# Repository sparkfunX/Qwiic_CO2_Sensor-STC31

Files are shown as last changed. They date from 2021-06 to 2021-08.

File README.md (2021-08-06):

SparkX CO<sub>2</sub> Sensor - STC31 (Qwiic)
========================================

SparkX CO2 Sensor - STC31 (Qwiic) (SPX-18385) (https://www.sparkfun.com/products/18385)

[*SparkX CO2 Sensor - STC31 (Qwiic) (SPX-18385)*](https://www.sparkfun.com/products/18385)

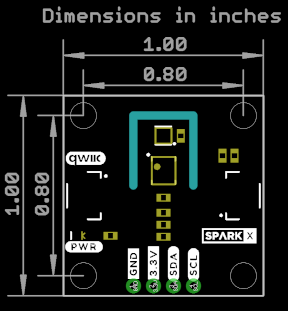
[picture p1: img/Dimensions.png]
SparkX CO2 Sensor - STC31 (Qwiic)


Do you need to be able to sense CO<sub>2</sub> concentrations of up to 100%? If so, the STC31 is the sensor for you!
The Sensirion STC31 thermal conductivity sensor has two CO<sub>2</sub> measurement ranges: 0 to 25 vol%; and 0 to 100 vol%.
The measurement repeatability is 0.2 vol%, with a stability of 0.025 vol% / °C.
The measurement accuracy depends on the measurement range: 0.5 vol% + 3% measured value; 1 vol% + 3% measured value.

Our breakout includes a separate SHTC3 humidity and temperature sensor; allowing the STC31 to deliver humidity-compensated
measurements together with improved temperature compensation. The STC31 can compensate for atmospheric pressure too - which is handy if,
like us, you’re up in the mountains!

The STC3x sensor family is Sensirion’s series of Gas Concentration sensors designed for high-volume applications.
The STC3x utilizes a revolutionized thermal conductivity measurement principle, which results in superior repeatability and long-term stability.
This makes the STC31 a perfect choice for applications where reliability is key.

The outstanding performance of these sensors is based on Sensirion’s patented CMOSens® sensor technology, which combines the sensor element,
signal processing and digital calibration on a small CMOS chip.
The well-proven CMOS technology is perfectly suited for high-quality mass production and is the ideal choice for demanding and cost-sensitive OEM applications.

Repository Contents
-------------------
* **/Documents** - datasheets etc.
* **/Hardware** - Eagle design files (.brd, .sch)
- **LICENSE.md** contains the licence information

Documentation
--------------
* **[STC3x Arduino Library](https://github.com/sparkfun/SparkFun_STC3x_Arduino_Library)** - Arduino library for the SparkX CO2 Sensor - STC31.
* **[Hookup Guide]()** - Basic hookup guide for the SparkX CO2 Sensor - STC31.

Product Versions
----------------
* [SPX-18385](https://www.sparkfun.com/products/18385) - Original SparkX Release.

License Information
-------------------

This product is _**open source**_!

Please review the LICENSE.md file for license information.

If you have any questions or concerns on licensing, please contact technical support on our [SparkFun forums](https://forum.sparkfun.com/viewforum.php?f=123).

Distributed as-is; no warranty is given.

- Your friends at SparkFun.

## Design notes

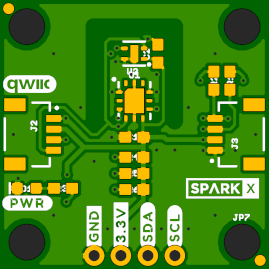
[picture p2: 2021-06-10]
img/Top.png

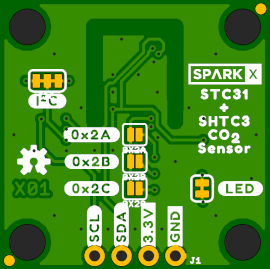
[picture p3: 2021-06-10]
img/Bottom.png

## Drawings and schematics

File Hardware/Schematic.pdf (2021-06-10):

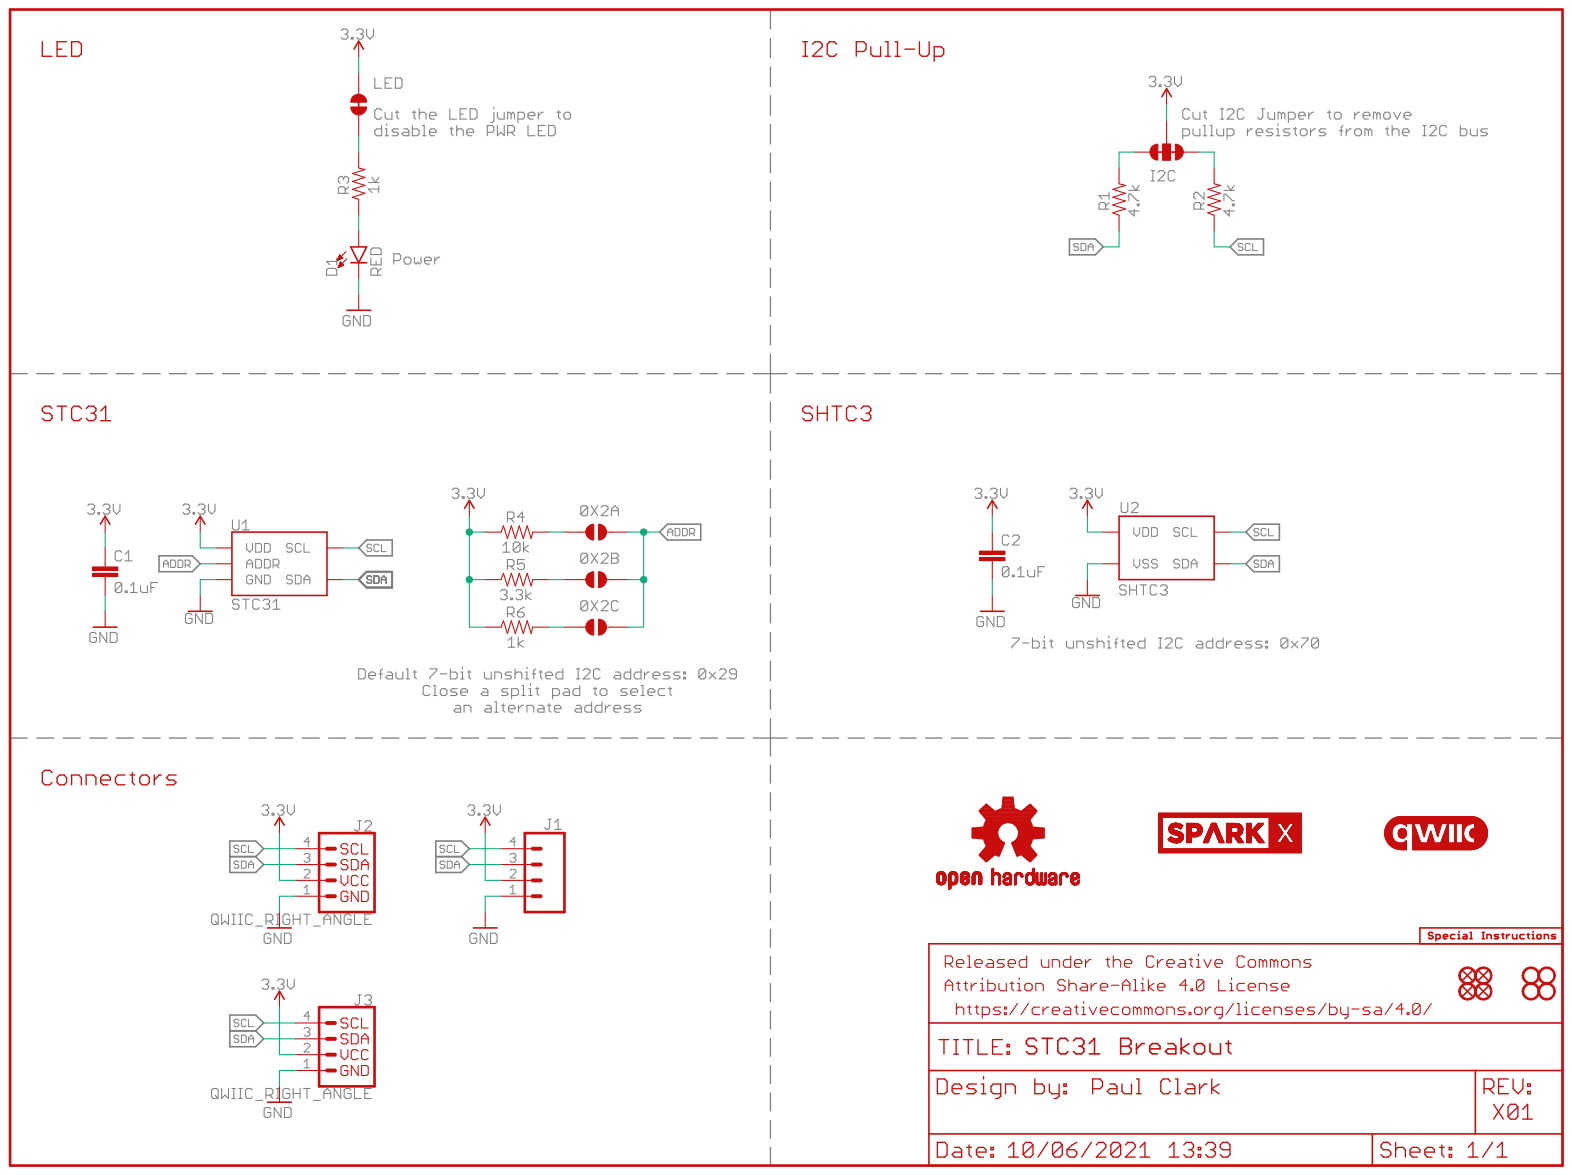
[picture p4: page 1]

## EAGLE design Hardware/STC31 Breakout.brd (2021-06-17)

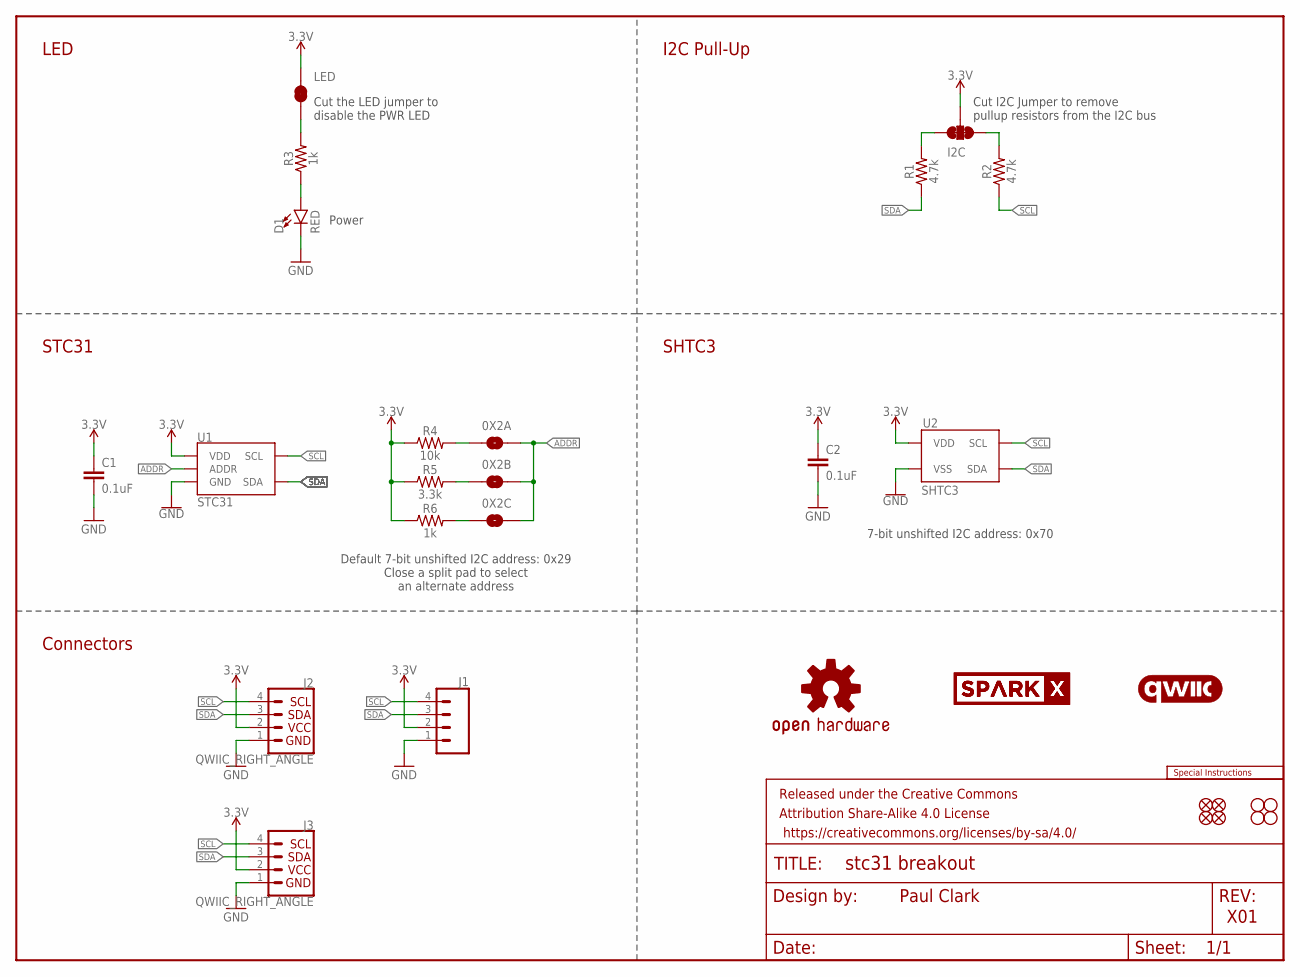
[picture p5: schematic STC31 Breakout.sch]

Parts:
0X2A, 0X2B, 0X2C: JUMPER-SMT_2_NO_SILK; SMT-JUMPER_2_NO_SILK
C1, C2: 0.1uF; 0603
D1: RED; LED-0603
FRAME1: FRAME-LETTER; CREATIVE_COMMONS
I2C: JUMPER-SMT_3_2-NC_TRACE_SILK; SMT-JUMPER_3_2-NC_TRACE_SILK
J1: CONN_041X04_NO_SILK; 1X04_NO_SILK
J2, J3: QWIIC_RIGHT_ANGLE; JST04_1MM_RA
JP1, JP2, JP5, JP6: FIDUCIAL1X2; FIDUCIAL-1X2
JP3, JP4, JP7, JP8: STAND-OFF
LED: JUMPER-SMT_2_NC_TRACE_SILK; SMT-JUMPER_2_NC_TRACE_SILK
LOGO1: SPECIAL_INSTRUCTIONS-ORDERING; ORDERING_INSTRUCTIONS
LOGO2: QWIIC_LOGO_5MM; QWIIC_5MM
LOGO5: OSHW-LOGOS; OSHW-LOGO-S
R1, R2: 4.7k; 0603
R3, R6: 1k; 0603
R4: 10k; 0603
R5: 3.3k; 0603
U1: STC31
U2: SHTC3
U$10, U$18: SPARKX-LOGO3; SPARKX-SMALL

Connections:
3.3V: C1.1, C2.1, I2C.2, J1.2, J2.2, J3.2, LED.2, R4.1, R5.1, R6.1, U1.6 (VDD), U2.1 (VDD)
ADDR: 0X2A.2, 0X2B.2, 0X2C.2, U1.3 (ADDR)
GND: C1.2, C2.2, D1.C, J1.1, J2.1, J3.1, U1.1 (GND), U1.5 (GND), U1.9 (GND), U1.11 (GND), U1.DIEPAD (GND), U2.4 (VSS), U2.5 (VSS)
unnamed: LED.1, R3.2
unnamed: I2C.3, R1.2
unnamed: D1.A, R3.1
unnamed: I2C.1, R2.2
unnamed: 0X2A.1, R4.2
unnamed: 0X2B.1, R5.2
unnamed: 0X2C.1, R6.2
SCL: J1.4, J2.4, J3.4, R2.1, U1.4 (SCL), U2.2 (SCL)
SDA: J1.3, J2.3, J3.3, R1.1, U1.7 (SDA), U2.3 (SDA)

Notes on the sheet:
Paul Clark
X01
7-bit unshifted I2C address: 0x70
Power
I2C Pull-Up
STC31
Connectors
Cut the LED jumper to disable the PWR LED
Cut I2C Jumper to remove pullup resistors from the I2C bus
LED
SHTC3
Default 7-bit unshifted I2C address: 0x29 Close a split pad to select an alternate address

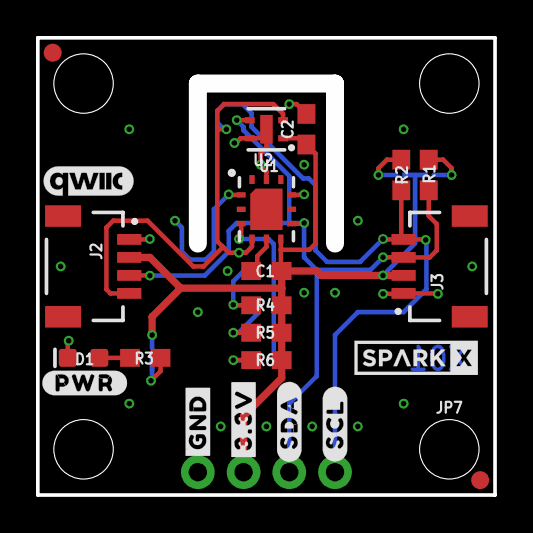
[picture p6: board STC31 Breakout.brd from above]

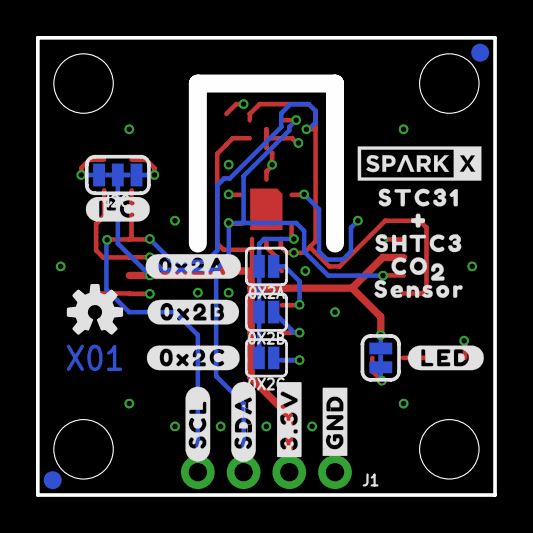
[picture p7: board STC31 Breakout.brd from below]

Board: 2 copper layers, 25.4 x 25.4 mm, 53 parts (25 on the bottom side), 12 nets.

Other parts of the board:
U$1, U$33: #GND#0
U$2, U$34: #3#3V#0
U$3, U$35: #SDA#0
U$4, U$36: #SCL#0
U$5: #LED#0
U$6: #0X2A#0
U$7: #0X2B#0
U$8: #0X2C#0
U$9: #I�C#0
U$11: STC310
U$12: #0
U$13: SHTC30
U$14: CO0
U$15: 20
U$16: SENSOR0
U$32: #PWR#0

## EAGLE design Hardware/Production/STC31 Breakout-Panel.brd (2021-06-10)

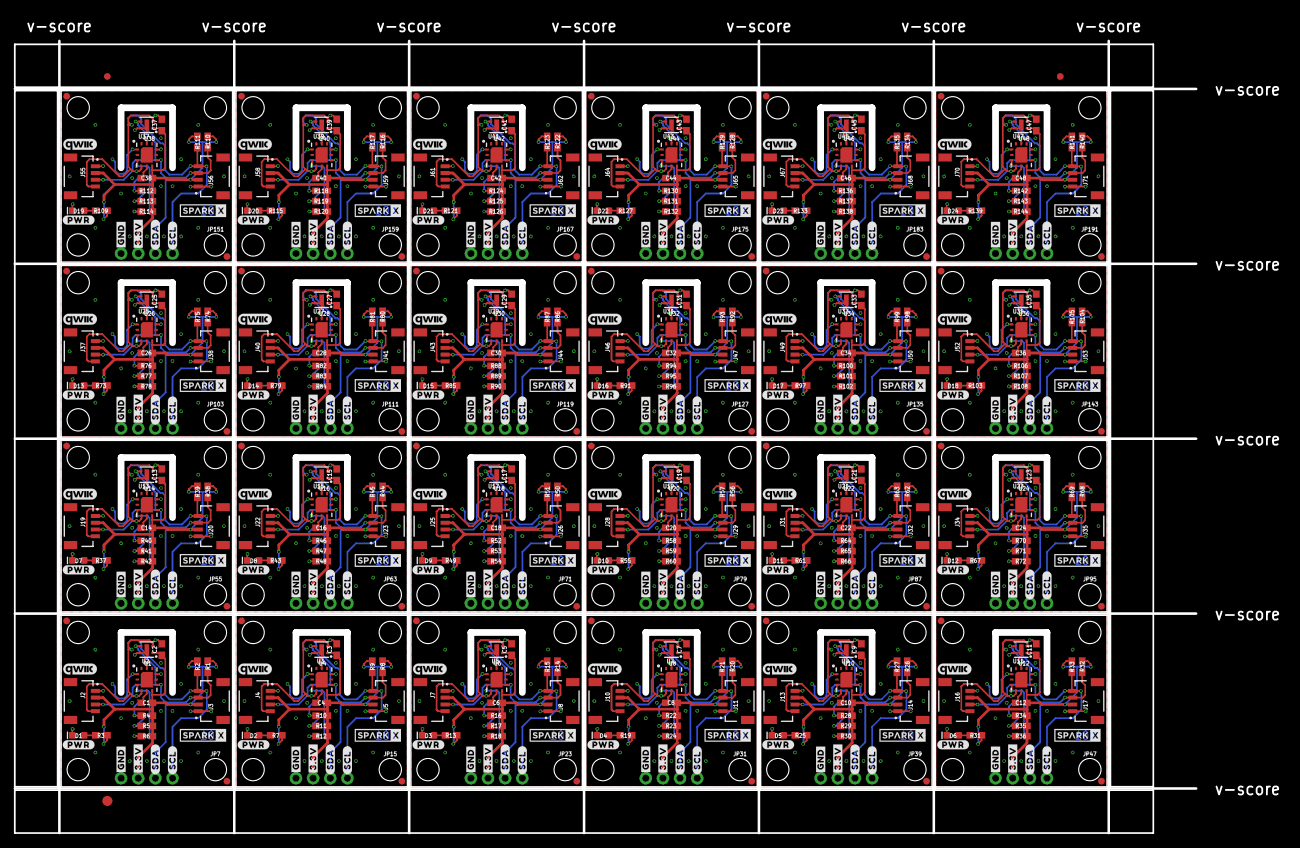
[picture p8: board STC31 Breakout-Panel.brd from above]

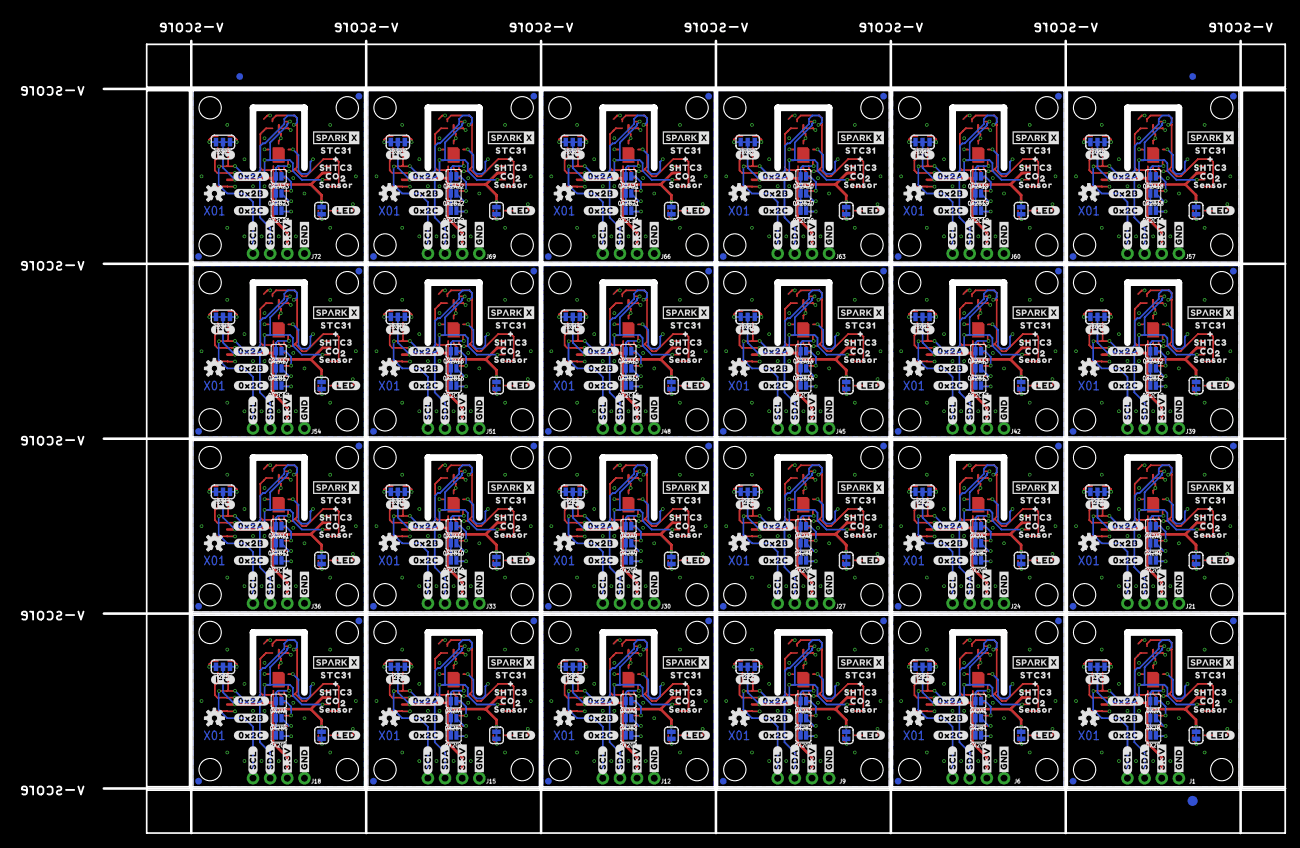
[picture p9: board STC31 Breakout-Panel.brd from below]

Board: 2 copper layers, 175.0 x 117.3 mm, 1230 parts (603 on the bottom side), 288 nets.

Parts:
0X2A, 0X2A1, 0X2A2, 0X2A3, 0X2A4, 0X2A5, 0X2A6, 0X2A7, 0X2A8, 0X2A9, 0X2A10, 0X2A11, 0X2A12, 0X2A13, 0X2A14, 0X2A15, 0X2A16, 0X2A17, 0X2A18, 0X2A19, 0X2A20, 0X2A21, 0X2A22, 0X2A23, 0X2B, 0X2B1, 0X2B2, 0X2B3, 0X2B4, 0X2B5, 0X2B6, 0X2B7, 0X2B8, 0X2B9, 0X2B10, 0X2B11, 0X2B12, 0X2B13, 0X2B14, 0X2B15, 0X2B16, 0X2B17, 0X2B18, 0X2B19, 0X2B20, 0X2B21, 0X2B22, 0X2B23, 0X2C, 0X2C1, 0X2C2, 0X2C3, 0X2C4, 0X2C5, 0X2C6, 0X2C7, 0X2C8, 0X2C9, 0X2C10, 0X2C11, 0X2C12, 0X2C13, 0X2C14, 0X2C15, 0X2C16, 0X2C17, 0X2C18, 0X2C19, 0X2C20, 0X2C21, 0X2C22, 0X2C23: JUMPER-SMT_2_NO_SILK; SMT-JUMPER_2_NO_SILK
C1, C2, C3, C4, C5, C6, C7, C8, C9, C10, C11, C12, C13, C14, C15, C16, C17, C18, C19, C20, C21, C22, C23, C24, C25, C26, C27, C28, C29, C30, C31, C32, C33, C34, C35, C36, C37, C38, C39, C40, C41, C42, C43, C44, C45, C46, C47, C48: 0.1uF; 0603
D1, D2, D3, D4, D5, D6, D7, D8, D9, D10, D11, D12, D13, D14, D15, D16, D17, D18, D19, D20, D21, D22, D23, D24: RED; LED-0603
E$1, E$2, E$3, E$4: FIDUCIAL-1X2
E$5, E$6: FIDUCIAL-1.5X3
I2C, I2C1, I2C2, I2C3, I2C4, I2C5, I2C6, I2C7, I2C8, I2C9, I2C10, I2C11, I2C12, I2C13, I2C14, I2C15, I2C16, I2C17, I2C18, I2C19, I2C20, I2C21, I2C22, I2C23: JUMPER-SMT_3_2-NC_TRACE_SILK; SMT-JUMPER_3_2-NC_TRACE_SILK
J1, J6, J9, J12, J15, J18, J21, J24, J27, J30, J33, J36, J39, J42, J45, J48, J51, J54, J57, J60, J63, J66, J69, J72: 1X04_NO_SILK
J2, J3, J4, J5, J7, J8, J10, J11, J13, J14, J16, J17, J19, J20, J22, J23, J25, J26, J28, J29, J31, J32, J34, J35, J37, J38, J40, J41, J43, J44, J46, J47, J49, J50, J52, J53, J55, J56, J58, J59, J61, J62, J64, J65, J67, J68, J70, J71: QWIIC_RIGHT_ANGLE; JST04_1MM_RA
JP1, JP2, JP5, JP6, JP11, JP12, JP13, JP14, JP19, JP20, JP21, JP22, JP27, JP28, JP29, JP30, JP35, JP36, JP37, JP38, JP43, JP44, JP45, JP46, JP51, JP52, JP53, JP54, JP59, JP60, JP61, JP62, JP67, JP68, JP69, JP70, JP75, JP76, JP77, JP78, JP83, JP84, JP85, JP86, JP91, JP92, JP93, JP94, JP99, JP100, JP101, JP102, JP107, JP108, JP109, JP110, JP115, JP116, JP117, JP118, JP123, JP124, JP125, JP126, JP131, JP132, JP133, JP134, JP139, JP140, JP141, JP142, JP147, JP148, JP149, JP150, JP155, JP156, JP157, JP158, JP163, JP164, JP165, JP166, JP171, JP172, JP173, JP174, JP179, JP180, JP181, JP182, JP187, JP188, JP189, JP190: FIDUCIAL1X2; FIDUCIAL-1X2
JP3, JP4, JP7, JP8, JP9, JP10, JP15, JP16, JP17, JP18, JP23, JP24, JP25, JP26, JP31, JP32, JP33, JP34, JP39, JP40, JP41, JP42, JP47, JP48, JP49, JP50, JP55, JP56, JP57, JP58, JP63, JP64, JP65, JP66, JP71, JP72, JP73, JP74, JP79, JP80, JP81, JP82, JP87, JP88, JP89, JP90, JP95, JP96, JP97, JP98, JP103, JP104, JP105, JP106, JP111, JP112, JP113, JP114, JP119, JP120, JP121, JP122, JP127, JP128, JP129, JP130, JP135, JP136, JP137, JP138, JP143, JP144, JP145, JP146, JP151, JP152, JP153, JP154, JP159, JP160, JP161, JP162, JP167, JP168, JP169, JP170, JP175, JP176, JP177, JP178, JP183, JP184, JP185, JP186, JP191, JP192: STAND-OFF
LED, LED1, LED2, LED3, LED4, LED5, LED6, LED7, LED8, LED9, LED10, LED11, LED12, LED13, LED14, LED15, LED16, LED17, LED18, LED19, LED20, LED21, LED22, LED23: JUMPER-SMT_2_NC_TRACE_SILK; SMT-JUMPER_2_NC_TRACE_SILK
LOGO1, LOGO4, LOGO5, LOGO7, LOGO9, LOGO11, LOGO13, LOGO15, LOGO17, LOGO19, LOGO21, LOGO23, LOGO25, LOGO27, LOGO29, LOGO31, LOGO33, LOGO35, LOGO37, LOGO39, LOGO41, LOGO43, LOGO45, LOGO47: OSHW-LOGOS; OSHW-LOGO-S
LOGO2, LOGO3, LOGO6, LOGO8, LOGO10, LOGO12, LOGO14, LOGO16, LOGO18, LOGO20, LOGO22, LOGO24, LOGO26, LOGO28, LOGO30, LOGO32, LOGO34, LOGO36, LOGO38, LOGO40, LOGO42, LOGO44, LOGO46, LOGO48: QWIIC_LOGO_5MM; QWIIC_5MM
R1, R2, R8, R9, R14, R15, R20, R21, R26, R27, R32, R33, R38, R39, R44, R45, R50, R51, R56, R57, R62, R63, R68, R69, R74, R75, R80, R81, R86, R87, R92, R93, R98, R99, R104, R105, R110, R111, R116, R117, R122, R123, R128, R129, R134, R135, R140, R141: 4.7k; 0603
R3, R6, R7, R12, R13, R18, R19, R24, R25, R30, R31, R36, R37, R42, R43, R48, R49, R54, R55, R60, R61, R66, R67, R72, R73, R78, R79, R84, R85, R90, R91, R96, R97, R102, R103, R108, R109, R114, R115, R120, R121, R126, R127, R132, R133, R138, R139, R144: 1k; 0603
R4, R10, R16, R22, R28, R34, R40, R46, R52, R58, R64, R70, R76, R82, R88, R94, R100, R106, R112, R118, R124, R130, R136, R142: 10k; 0603
R5, R11, R17, R23, R29, R35, R41, R47, R53, R59, R65, R71, R77, R83, R89, R95, R101, R107, R113, R119, R125, R131, R137, R143: 3.3k; 0603
U1, U4, U6, U8, U10, U12, U14, U16, U18, U20, U22, U24, U26, U28, U30, U32, U34, U36, U38, U40, U42, U44, U46, U48: STC31
U2, U3, U5, U7, U9, U11, U13, U15, U17, U19, U21, U23, U25, U27, U29, U31, U33, U35, U37, U39, U41, U43, U45, U47: SHTC3
U$1, U$21, U$25, U$33, U$48, U$52, U$70, U$74, U$92, U$96, U$114, U$118, U$136, U$140, U$158, U$162, U$180, U$184, U$202, U$206, U$224, U$228, U$246, U$250, U$268, U$272, U$290, U$294, U$312, U$316, U$334, U$338, U$356, U$360, U$378, U$382, U$400, U$404, U$422, U$426, U$444, U$448, U$466, U$470, U$488, U$492, U$510, U$514: #GND#0
U$2, U$22, U$26, U$34, U$49, U$53, U$71, U$75, U$93, U$97, U$115, U$119, U$137, U$141, U$159, U$163, U$181, U$185, U$203, U$207, U$225, U$229, U$247, U$251, U$269, U$273, U$291, U$295, U$313, U$317, U$335, U$339, U$357, U$361, U$379, U$383, U$401, U$405, U$423, U$427, U$445, U$449, U$467, U$471, U$489, U$493, U$511, U$515: #3#3V#0
U$3, U$23, U$27, U$35, U$50, U$54, U$72, U$76, U$94, U$98, U$116, U$120, U$138, U$142, U$160, U$164, U$182, U$186, U$204, U$208, U$226, U$230, U$248, U$252, U$270, U$274, U$292, U$296, U$314, U$318, U$336, U$340, U$358, U$362, U$380, U$384, U$402, U$406, U$424, U$428, U$446, U$450, U$468, U$472, U$490, U$494, U$512, U$516: #SDA#0
U$4, U$24, U$28, U$36, U$51, U$55, U$73, U$77, U$95, U$99, U$117, U$121, U$139, U$143, U$161, U$165, U$183, U$187, U$205, U$209, U$227, U$231, U$249, U$253, U$271, U$275, U$293, U$297, U$315, U$319, U$337, U$341, U$359, U$363, U$381, U$385, U$403, U$407, U$425, U$429, U$447, U$451, U$469, U$473, U$491, U$495, U$513, U$517: #SCL#0
U$5, U$29, U$56, U$78, U$100, U$122, U$144, U$166, U$188, U$210, U$232, U$254, U$276, U$298, U$320, U$342, U$364, U$386, U$408, U$430, U$452, U$474, U$496, U$518: #LED#0
U$6, U$30, U$57, U$79, U$101, U$123, U$145, U$167, U$189, U$211, U$233, U$255, U$277, U$299, U$321, U$343, U$365, U$387, U$409, U$431, U$453, U$475, U$497, U$519: #0X2A#0
U$7, U$31, U$58, U$80, U$102, U$124, U$146, U$168, U$190, U$212, U$234, U$256, U$278, U$300, U$322, U$344, U$366, U$388, U$410, U$432, U$454, U$476, U$498, U$520: #0X2B#0
U$8, U$37, U$59, U$81, U$103, U$125, U$147, U$169, U$191, U$213, U$235, U$257, U$279, U$301, U$323, U$345, U$367, U$389, U$411, U$433, U$455, U$477, U$499, U$521: #0X2C#0
U$9, U$38, U$60, U$82, U$104, U$126, U$148, U$170, U$192, U$214, U$236, U$258, U$280, U$302, U$324, U$346, U$368, U$390, U$412, U$434, U$456, U$478, U$500, U$522: #I�C#0
U$10, U$17, U$18, U$19, U$45, U$46, U$67, U$68, U$89, U$90, U$111, U$112, U$133, U$134, U$155, U$156, U$177, U$178, U$199, U$200, U$221, U$222, U$243, U$244, U$265, U$266, U$287, U$288, U$309, U$310, U$331, U$332, U$353, U$354, U$375, U$376, U$397, U$398, U$419, U$420, U$441, U$442, U$463, U$464, U$485, U$486, U$507, U$508: SPARKX-LOGO3; SPARKX-SMALL
U$11, U$39, U$61, U$83, U$105, U$127, U$149, U$171, U$193, U$215, U$237, U$259, U$281, U$303, U$325, U$347, U$369, U$391, U$413, U$435, U$457, U$479, U$501, U$523: STC310
U$12, U$40, U$62, U$84, U$106, U$128, U$150, U$172, U$194, U$216, U$238, U$260, U$282, U$304, U$326, U$348, U$370, U$392, U$414, U$436, U$458, U$480, U$502, U$524: #0
U$13, U$41, U$63, U$85, U$107, U$129, U$151, U$173, U$195, U$217, U$239, U$261, U$283, U$305, U$327, U$349, U$371, U$393, U$415, U$437, U$459, U$481, U$503, U$525: SHTC30
U$14, U$42, U$64, U$86, U$108, U$130, U$152, U$174, U$196, U$218, U$240, U$262, U$284, U$306, U$328, U$350, U$372, U$394, U$416, U$438, U$460, U$482, U$504, U$526: CO0
U$15, U$43, U$65, U$87, U$109, U$131, U$153, U$175, U$197, U$219, U$241, U$263, U$285, U$307, U$329, U$351, U$373, U$395, U$417, U$439, U$461, U$483, U$505, U$527: 20
U$16, U$44, U$66, U$88, U$110, U$132, U$154, U$176, U$198, U$220, U$242, U$264, U$286, U$308, U$330, U$352, U$374, U$396, U$418, U$440, U$462, U$484, U$506, U$528: SENSOR0
U$20, U$32, U$47, U$69, U$91, U$113, U$135, U$157, U$179, U$201, U$223, U$245, U$267, U$289, U$311, U$333, U$355, U$377, U$399, U$421, U$443, U$465, U$487, U$509: #PWR#0

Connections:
3.3V: C1.1, C2.1, I2C.2, J1.2, J2.2, J3.2, LED.2, R4.1, R5.1, R6.1, U1.6, U2.1
3.3V1: C3.1, C4.1, I2C1.2, J4.2, J5.2, J6.2, LED1.2, R10.1, R11.1, R12.1, U3.1, U4.6
3.3V2: C5.1, C6.1, I2C2.2, J7.2, J8.2, J9.2, LED2.2, R16.1, R17.1, R18.1, U5.1, U6.6
3.3V3: C7.1, C8.1, I2C3.2, J10.2, J11.2, J12.2, LED3.2, R22.1, R23.1, R24.1, U7.1, U8.6
3.3V4: C9.1, C10.1, I2C4.2, J13.2, J14.2, J15.2, LED4.2, R28.1, R29.1, R30.1, U9.1, U10.6
3.3V5: C11.1, C12.1, I2C5.2, J16.2, J17.2, J18.2, LED5.2, R34.1, R35.1, R36.1, U11.1, U12.6
3.3V6: C13.1, C14.1, I2C6.2, J19.2, J20.2, J21.2, LED6.2, R40.1, R41.1, R42.1, U13.1, U14.6
3.3V7: C15.1, C16.1, I2C7.2, J22.2, J23.2, J24.2, LED7.2, R46.1, R47.1, R48.1, U15.1, U16.6
3.3V8: C17.1, C18.1, I2C8.2, J25.2, J26.2, J27.2, LED8.2, R52.1, R53.1, R54.1, U17.1, U18.6
3.3V9: C19.1, C20.1, I2C9.2, J28.2, J29.2, J30.2, LED9.2, R58.1, R59.1, R60.1, U19.1, U20.6
3.3V10: C21.1, C22.1, I2C10.2, J31.2, J32.2, J33.2, LED10.2, R64.1, R65.1, R66.1, U21.1, U22.6
3.3V11: C23.1, C24.1, I2C11.2, J34.2, J35.2, J36.2, LED11.2, R70.1, R71.1, R72.1, U23.1, U24.6
3.3V12: C25.1, C26.1, I2C12.2, J37.2, J38.2, J39.2, LED12.2, R76.1, R77.1, R78.1, U25.1, U26.6
3.3V13: C27.1, C28.1, I2C13.2, J40.2, J41.2, J42.2, LED13.2, R82.1, R83.1, R84.1, U27.1, U28.6
3.3V14: C29.1, C30.1, I2C14.2, J43.2, J44.2, J45.2, LED14.2, R88.1, R89.1, R90.1, U29.1, U30.6
3.3V15: C31.1, C32.1, I2C15.2, J46.2, J47.2, J48.2, LED15.2, R94.1, R95.1, R96.1, U31.1, U32.6
3.3V16: C33.1, C34.1, I2C16.2, J49.2, J50.2, J51.2, LED16.2, R100.1, R101.1, R102.1, U33.1, U34.6
3.3V17: C35.1, C36.1, I2C17.2, J52.2, J53.2, J54.2, LED17.2, R106.1, R107.1, R108.1, U35.1, U36.6
3.3V18: C37.1, C38.1, I2C18.2, J55.2, J56.2, J57.2, LED18.2, R112.1, R113.1, R114.1, U37.1, U38.6
3.3V19: C39.1, C40.1, I2C19.2, J58.2, J59.2, J60.2, LED19.2, R118.1, R119.1, R120.1, U39.1, U40.6
3.3V20: C41.1, C42.1, I2C20.2, J61.2, J62.2, J63.2, LED20.2, R124.1, R125.1, R126.1, U41.1, U42.6
3.3V21: C43.1, C44.1, I2C21.2, J64.2, J65.2, J66.2, LED21.2, R130.1, R131.1, R132.1, U43.1, U44.6
3.3V22: C45.1, C46.1, I2C22.2, J67.2, J68.2, J69.2, LED22.2, R136.1, R137.1, R138.1, U45.1, U46.6
3.3V23: C47.1, C48.1, I2C23.2, J70.2, J71.2, J72.2, LED23.2, R142.1, R143.1, R144.1, U47.1, U48.6
ADDR: 0X2A.2, 0X2B.2, 0X2C.2, U1.3
ADDR1: 0X2A1.2, 0X2B1.2, 0X2C1.2, U4.3
ADDR2: 0X2A2.2, 0X2B2.2, 0X2C2.2, U6.3
ADDR3: 0X2A3.2, 0X2B3.2, 0X2C3.2, U8.3
ADDR4: 0X2A4.2, 0X2B4.2, 0X2C4.2, U10.3
ADDR5: 0X2A5.2, 0X2B5.2, 0X2C5.2, U12.3
ADDR6: 0X2A6.2, 0X2B6.2, 0X2C6.2, U14.3
ADDR7: 0X2A7.2, 0X2B7.2, 0X2C7.2, U16.3
ADDR8: 0X2A8.2, 0X2B8.2, 0X2C8.2, U18.3
ADDR9: 0X2A9.2, 0X2B9.2, 0X2C9.2, U20.3
ADDR10: 0X2A10.2, 0X2B10.2, 0X2C10.2, U22.3
ADDR11: 0X2A11.2, 0X2B11.2, 0X2C11.2, U24.3
ADDR12: 0X2A12.2, 0X2B12.2, 0X2C12.2, U26.3
ADDR13: 0X2A13.2, 0X2B13.2, 0X2C13.2, U28.3
ADDR14: 0X2A14.2, 0X2B14.2, 0X2C14.2, U30.3
ADDR15: 0X2A15.2, 0X2B15.2, 0X2C15.2, U32.3
ADDR16: 0X2A16.2, 0X2B16.2, 0X2C16.2, U34.3
ADDR17: 0X2A17.2, 0X2B17.2, 0X2C17.2, U36.3
ADDR18: 0X2A18.2, 0X2B18.2, 0X2C18.2, U38.3
ADDR19: 0X2A19.2, 0X2B19.2, 0X2C19.2, U40.3
ADDR20: 0X2A20.2, 0X2B20.2, 0X2C20.2, U42.3
ADDR21: 0X2A21.2, 0X2B21.2, 0X2C21.2, U44.3
ADDR22: 0X2A22.2, 0X2B22.2, 0X2C22.2, U46.3
ADDR23: 0X2A23.2, 0X2B23.2, 0X2C23.2, U48.3
GND: C1.2, C2.2, D1.C, J1.1, J2.1, J3.1, U1.1, U1.5, U1.9, U1.11, U1.DIEPAD, U2.4, U2.5
GND1: C3.2, C4.2, D2.C, J4.1, J5.1, J6.1, U3.4, U3.5, U4.1, U4.5, U4.9, U4.11, U4.DIEPAD
GND2: C5.2, C6.2, D3.C, J7.1, J8.1, J9.1, U5.4, U5.5, U6.1, U6.5, U6.9, U6.11, U6.DIEPAD
GND3: C7.2, C8.2, D4.C, J10.1, J11.1, J12.1, U7.4, U7.5, U8.1, U8.5, U8.9, U8.11, U8.DIEPAD
GND4: C9.2, C10.2, D5.C, J13.1, J14.1, J15.1, U9.4, U9.5, U10.1, U10.5, U10.9, U10.11, U10.DIEPAD
GND5: C11.2, C12.2, D6.C, J16.1, J17.1, J18.1, U11.4, U11.5, U12.1, U12.5, U12.9, U12.11, U12.DIEPAD
GND6: C13.2, C14.2, D7.C, J19.1, J20.1, J21.1, U13.4, U13.5, U14.1, U14.5, U14.9, U14.11, U14.DIEPAD
GND7: C15.2, C16.2, D8.C, J22.1, J23.1, J24.1, U15.4, U15.5, U16.1, U16.5, U16.9, U16.11, U16.DIEPAD
GND8: C17.2, C18.2, D9.C, J25.1, J26.1, J27.1, U17.4, U17.5, U18.1, U18.5, U18.9, U18.11, U18.DIEPAD
GND9: C19.2, C20.2, D10.C, J28.1, J29.1, J30.1, U19.4, U19.5, U20.1, U20.5, U20.9, U20.11, U20.DIEPAD
GND10: C21.2, C22.2, D11.C, J31.1, J32.1, J33.1, U21.4, U21.5, U22.1, U22.5, U22.9, U22.11, U22.DIEPAD
GND11: C23.2, C24.2, D12.C, J34.1, J35.1, J36.1, U23.4, U23.5, U24.1, U24.5, U24.9, U24.11, U24.DIEPAD
GND12: C25.2, C26.2, D13.C, J37.1, J38.1, J39.1, U25.4, U25.5, U26.1, U26.5, U26.9, U26.11, U26.DIEPAD
GND13: C27.2, C28.2, D14.C, J40.1, J41.1, J42.1, U27.4, U27.5, U28.1, U28.5, U28.9, U28.11, U28.DIEPAD
GND14: C29.2, C30.2, D15.C, J43.1, J44.1, J45.1, U29.4, U29.5, U30.1, U30.5, U30.9, U30.11, U30.DIEPAD
GND15: C31.2, C32.2, D16.C, J46.1, J47.1, J48.1, U31.4, U31.5, U32.1, U32.5, U32.9, U32.11, U32.DIEPAD
GND16: C33.2, C34.2, D17.C, J49.1, J50.1, J51.1, U33.4, U33.5, U34.1, U34.5, U34.9, U34.11, U34.DIEPAD
GND17: C35.2, C36.2, D18.C, J52.1, J53.1, J54.1, U35.4, U35.5, U36.1, U36.5, U36.9, U36.11, U36.DIEPAD
GND18: C37.2, C38.2, D19.C, J55.1, J56.1, J57.1, U37.4, U37.5, U38.1, U38.5, U38.9, U38.11, U38.DIEPAD
GND19: C39.2, C40.2, D20.C, J58.1, J59.1, J60.1, U39.4, U39.5, U40.1, U40.5, U40.9, U40.11, U40.DIEPAD
GND20: C41.2, C42.2, D21.C, J61.1, J62.1, J63.1, U41.4, U41.5, U42.1, U42.5, U42.9, U42.11, U42.DIEPAD
GND21: C43.2, C44.2, D22.C, J64.1, J65.1, J66.1, U43.4, U43.5, U44.1, U44.5, U44.9, U44.11, U44.DIEPAD
GND22: C45.2, C46.2, D23.C, J67.1, J68.1, J69.1, U45.4, U45.5, U46.1, U46.5, U46.9, U46.11, U46.DIEPAD
GND23: C47.2, C48.2, D24.C, J70.1, J71.1, J72.1, U47.4, U47.5, U48.1, U48.5, U48.9, U48.11, U48.DIEPAD
unnamed: LED.1, R3.2
unnamed: I2C.3, R1.2
unnamed: D1.A, R3.1
unnamed: I2C.1, R2.2
unnamed: 0X2A.1, R4.2
unnamed: 0X2B.1, R5.2
unnamed: 0X2C.1, R6.2
unnamed: D2.A, R7.1
unnamed: LED1.1, R7.2
unnamed: I2C1.3, R8.2
unnamed: I2C1.1, R9.2
unnamed: 0X2A1.1, R10.2
unnamed: 0X2B1.1, R11.2
unnamed: 0X2C1.1, R12.2
unnamed: D3.A, R13.1
unnamed: LED2.1, R13.2
unnamed: I2C2.3, R14.2
unnamed: I2C2.1, R15.2
unnamed: 0X2A2.1, R16.2
unnamed: 0X2B2.1, R17.2
unnamed: 0X2C2.1, R18.2
unnamed: D4.A, R19.1
unnamed: LED3.1, R19.2
unnamed: I2C3.3, R20.2
unnamed: I2C3.1, R21.2
unnamed: 0X2A3.1, R22.2
unnamed: 0X2B3.1, R23.2
unnamed: 0X2C3.1, R24.2
unnamed: D5.A, R25.1
unnamed: LED4.1, R25.2
unnamed: I2C4.3, R26.2
unnamed: I2C4.1, R27.2
unnamed: 0X2A4.1, R28.2
unnamed: 0X2B4.1, R29.2
unnamed: 0X2C4.1, R30.2
unnamed: D6.A, R31.1
unnamed: LED5.1, R31.2
unnamed: I2C5.3, R32.2
unnamed: I2C5.1, R33.2
unnamed: 0X2A5.1, R34.2
unnamed: 0X2B5.1, R35.2
unnamed: 0X2C5.1, R36.2
unnamed: D7.A, R37.1
unnamed: LED6.1, R37.2
unnamed: I2C6.3, R38.2
unnamed: I2C6.1, R39.2
unnamed: 0X2A6.1, R40.2
unnamed: 0X2B6.1, R41.2
unnamed: 0X2C6.1, R42.2
unnamed: D8.A, R43.1
unnamed: LED7.1, R43.2
unnamed: I2C7.3, R44.2
unnamed: I2C7.1, R45.2
unnamed: 0X2A7.1, R46.2
unnamed: 0X2B7.1, R47.2
unnamed: 0X2C7.1, R48.2
unnamed: D9.A, R49.1
unnamed: LED8.1, R49.2
unnamed: I2C8.3, R50.2
unnamed: I2C8.1, R51.2
unnamed: 0X2A8.1, R52.2
unnamed: 0X2B8.1, R53.2
unnamed: 0X2C8.1, R54.2
unnamed: D10.A, R55.1
unnamed: LED9.1, R55.2
unnamed: I2C9.3, R56.2
unnamed: I2C9.1, R57.2
unnamed: 0X2A9.1, R58.2
unnamed: 0X2B9.1, R59.2
unnamed: 0X2C9.1, R60.2
unnamed: D11.A, R61.1
unnamed: LED10.1, R61.2
unnamed: I2C10.3, R62.2
unnamed: I2C10.1, R63.2
unnamed: 0X2A10.1, R64.2
unnamed: 0X2B10.1, R65.2
unnamed: 0X2C10.1, R66.2
unnamed: D12.A, R67.1
unnamed: LED11.1, R67.2
unnamed: I2C11.3, R68.2
unnamed: I2C11.1, R69.2
unnamed: 0X2A11.1, R70.2
unnamed: 0X2B11.1, R71.2
unnamed: 0X2C11.1, R72.2
unnamed: D13.A, R73.1
unnamed: LED12.1, R73.2
unnamed: I2C12.3, R74.2
unnamed: I2C12.1, R75.2
unnamed: 0X2A12.1, R76.2
unnamed: 0X2B12.1, R77.2
unnamed: 0X2C12.1, R78.2
unnamed: D14.A, R79.1
unnamed: LED13.1, R79.2
unnamed: I2C13.3, R80.2
unnamed: I2C13.1, R81.2
unnamed: 0X2A13.1, R82.2
unnamed: 0X2B13.1, R83.2
unnamed: 0X2C13.1, R84.2
unnamed: D15.A, R85.1
unnamed: LED14.1, R85.2
unnamed: I2C14.3, R86.2
unnamed: I2C14.1, R87.2
unnamed: 0X2A14.1, R88.2
unnamed: 0X2B14.1, R89.2
unnamed: 0X2C14.1, R90.2
unnamed: D16.A, R91.1
unnamed: LED15.1, R91.2
unnamed: I2C15.3, R92.2
unnamed: I2C15.1, R93.2
unnamed: 0X2A15.1, R94.2
unnamed: 0X2B15.1, R95.2
unnamed: 0X2C15.1, R96.2
unnamed: D17.A, R97.1
unnamed: LED16.1, R97.2
unnamed: I2C16.3, R98.2
unnamed: I2C16.1, R99.2
unnamed: 0X2A16.1, R100.2
unnamed: 0X2B16.1, R101.2
unnamed: 0X2C16.1, R102.2
unnamed: D18.A, R103.1
unnamed: LED17.1, R103.2
unnamed: I2C17.3, R104.2
unnamed: I2C17.1, R105.2
unnamed: 0X2A17.1, R106.2
unnamed: 0X2B17.1, R107.2
unnamed: 0X2C17.1, R108.2
unnamed: D19.A, R109.1
unnamed: LED18.1, R109.2
unnamed: I2C18.3, R110.2
unnamed: I2C18.1, R111.2
unnamed: 0X2A18.1, R112.2
unnamed: 0X2B18.1, R113.2
unnamed: 0X2C18.1, R114.2
unnamed: D20.A, R115.1
unnamed: LED19.1, R115.2
unnamed: I2C19.3, R116.2
unnamed: I2C19.1, R117.2
unnamed: 0X2A19.1, R118.2
unnamed: 0X2B19.1, R119.2
unnamed: 0X2C19.1, R120.2
unnamed: D21.A, R121.1
unnamed: LED20.1, R121.2
unnamed: I2C20.3, R122.2
unnamed: I2C20.1, R123.2
unnamed: 0X2A20.1, R124.2
unnamed: 0X2B20.1, R125.2
unnamed: 0X2C20.1, R126.2
unnamed: D22.A, R127.1
unnamed: LED21.1, R127.2
unnamed: I2C21.3, R128.2
unnamed: I2C21.1, R129.2
unnamed: 0X2A21.1, R130.2
unnamed: 0X2B21.1, R131.2
unnamed: 0X2C21.1, R132.2
unnamed: D23.A, R133.1
unnamed: LED22.1, R133.2
unnamed: I2C22.3, R134.2
unnamed: I2C22.1, R135.2
unnamed: 0X2A22.1, R136.2
unnamed: 0X2B22.1, R137.2
unnamed: 0X2C22.1, R138.2
unnamed: D24.A, R139.1
unnamed: LED23.1, R139.2
unnamed: I2C23.3, R140.2
unnamed: I2C23.1, R141.2
unnamed: 0X2A23.1, R142.2
unnamed: 0X2B23.1, R143.2
unnamed: 0X2C23.1, R144.2
SCL: J1.4, J2.4, J3.4, R2.1, U1.4, U2.2
SCL1: J4.4, J5.4, J6.4, R9.1, U3.2, U4.4
SCL2: J7.4, J8.4, J9.4, R15.1, U5.2, U6.4
SCL3: J10.4, J11.4, J12.4, R21.1, U7.2, U8.4
SCL4: J13.4, J14.4, J15.4, R27.1, U9.2, U10.4
SCL5: J16.4, J17.4, J18.4, R33.1, U11.2, U12.4
SCL6: J19.4, J20.4, J21.4, R39.1, U13.2, U14.4
SCL7: J22.4, J23.4, J24.4, R45.1, U15.2, U16.4
SCL8: J25.4, J26.4, J27.4, R51.1, U17.2, U18.4
SCL9: J28.4, J29.4, J30.4, R57.1, U19.2, U20.4
SCL10: J31.4, J32.4, J33.4, R63.1, U21.2, U22.4
SCL11: J34.4, J35.4, J36.4, R69.1, U23.2, U24.4
SCL12: J37.4, J38.4, J39.4, R75.1, U25.2, U26.4
SCL13: J40.4, J41.4, J42.4, R81.1, U27.2, U28.4
SCL14: J43.4, J44.4, J45.4, R87.1, U29.2, U30.4
SCL15: J46.4, J47.4, J48.4, R93.1, U31.2, U32.4
SCL16: J49.4, J50.4, J51.4, R99.1, U33.2, U34.4
SCL17: J52.4, J53.4, J54.4, R105.1, U35.2, U36.4
SCL18: J55.4, J56.4, J57.4, R111.1, U37.2, U38.4
SCL19: J58.4, J59.4, J60.4, R117.1, U39.2, U40.4
SCL20: J61.4, J62.4, J63.4, R123.1, U41.2, U42.4
SCL21: J64.4, J65.4, J66.4, R129.1, U43.2, U44.4
SCL22: J67.4, J68.4, J69.4, R135.1, U45.2, U46.4
SCL23: J70.4, J71.4, J72.4, R141.1, U47.2, U48.4
SDA: J1.3, J2.3, J3.3, R1.1, U1.7, U2.3
SDA1: J4.3, J5.3, J6.3, R8.1, U3.3, U4.7
SDA2: J7.3, J8.3, J9.3, R14.1, U5.3, U6.7
SDA3: J10.3, J11.3, J12.3, R20.1, U7.3, U8.7
SDA4: J13.3, J14.3, J15.3, R26.1, U9.3, U10.7
SDA5: J16.3, J17.3, J18.3, R32.1, U11.3, U12.7
SDA6: J19.3, J20.3, J21.3, R38.1, U13.3, U14.7
SDA7: J22.3, J23.3, J24.3, R44.1, U15.3, U16.7
SDA8: J25.3, J26.3, J27.3, R50.1, U17.3, U18.7
SDA9: J28.3, J29.3, J30.3, R56.1, U19.3, U20.7
SDA10: J31.3, J32.3, J33.3, R62.1, U21.3, U22.7
SDA11: J34.3, J35.3, J36.3, R68.1, U23.3, U24.7
SDA12: J37.3, J38.3, J39.3, R74.1, U25.3, U26.7
SDA13: J40.3, J41.3, J42.3, R80.1, U27.3, U28.7
SDA14: J43.3, J44.3, J45.3, R86.1, U29.3, U30.7
SDA15: J46.3, J47.3, J48.3, R92.1, U31.3, U32.7
SDA16: J49.3, J50.3, J51.3, R98.1, U33.3, U34.7
SDA17: J52.3, J53.3, J54.3, R104.1, U35.3, U36.7
SDA18: J55.3, J56.3, J57.3, R110.1, U37.3, U38.7
SDA19: J58.3, J59.3, J60.3, R116.1, U39.3, U40.7
SDA20: J61.3, J62.3, J63.3, R122.1, U41.3, U42.7
SDA21: J64.3, J65.3, J66.3, R128.1, U43.3, U44.7
SDA22: J67.3, J68.3, J69.3, R134.1, U45.3, U46.7
SDA23: J70.3, J71.3, J72.3, R140.1, U47.3, U48.7

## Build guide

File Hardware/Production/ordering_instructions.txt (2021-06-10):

panel size, 169x117mm
PCB thickness, 1.6mm
number of layers, 2
soldermask color, Black
silkscreen color, White
oz copper, 1oz
finish, HASL lead free
stencils, top
pcs per panel, 24
min trace width, 0.2540mm / 0.0100in
min drill size, 0.3000mm / 0.0118in

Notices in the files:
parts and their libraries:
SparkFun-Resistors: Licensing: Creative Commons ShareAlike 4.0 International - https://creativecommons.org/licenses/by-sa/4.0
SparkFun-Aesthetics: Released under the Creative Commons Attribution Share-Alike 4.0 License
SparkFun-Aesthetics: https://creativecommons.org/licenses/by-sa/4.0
